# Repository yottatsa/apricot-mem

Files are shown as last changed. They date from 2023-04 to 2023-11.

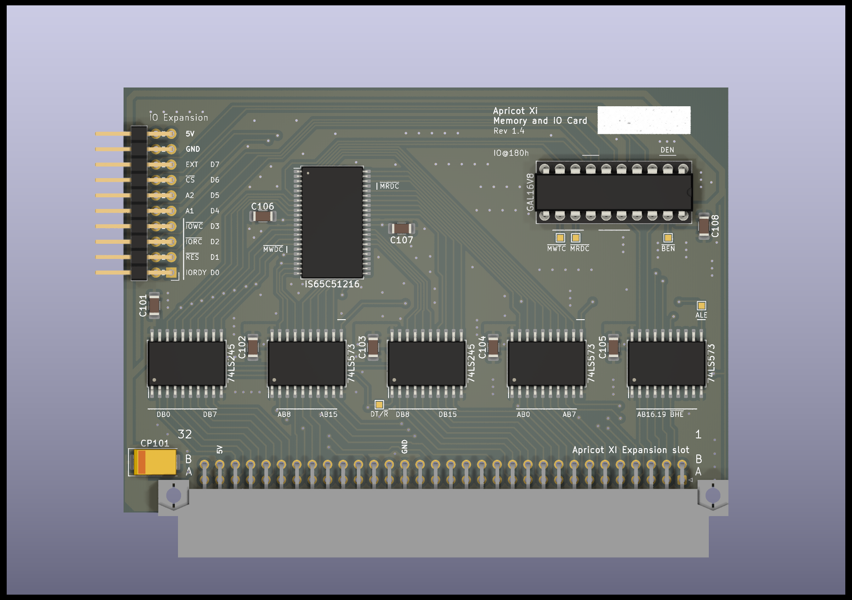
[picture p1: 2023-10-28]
apricot-mem.png

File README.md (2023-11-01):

# Apricot Xi Memory and IO Card 

Additional 640KB RAM, and IO breakout for prototyping.

Tested on PC/Xi, FP. Should be working on F2/F10. Not working on F1e with 128K RAM.

[Schematics](https://kicanvas.org/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), 
[PCB](https://kicanvas.org/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), [Order from AISLER](https://aisler.net/p/DJKRDMKA)

## Building and flashing GAL

    make -C gal
    minipro -p ATF16V8C --write gal/xi.jed -P

## ToDo

* Loading caps on signal lines
* Move GAL to the left so it will be accessible without pulling the card
* Move testpoints to the bottom/make them THT, as it will make it more accessible from the case
* 3D-print a frame to hold the card in place
* DT/R̅ can be latched

## Board verification

- GAL is compilable and flash-able
- pins 12, 19 can not be used as input in registered mode

## Alternative options

* [Apricot F Series expandable SRAM board](https://github.com/stephen-usher/Apricot-RAM-Expansion) by S.R.Usher

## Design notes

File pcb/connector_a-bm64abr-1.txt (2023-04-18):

"Symbol";"Value";"Unit";
"TraceParts.PartNumber";"10-27072010-079244";"";
"REFERENCE";"A-BM64ABR-1";"";
"TraceParts.PartTitle";"DIN 41612, style B, male, 16 - 64 contacts, pitch 2.54mm";"";
"TraceParts.InstanceId";"10-27072010-079244AF7FB7TEG8P7RZZJ1AFMGNGAB";"";
"SUPPLIER";"ASSMANN WSW components";"";
"DESIGN";"DIN 41612, style B, male, pitch 2.54mm, 64ab contacts, Right-angled, Class 1";"";
"TRACEPARTS";"TRACEPARTS";"";
"TraceParts.PartLanguage";"en";"";
"TraceParts.PartVersion";"1.1.8";"";

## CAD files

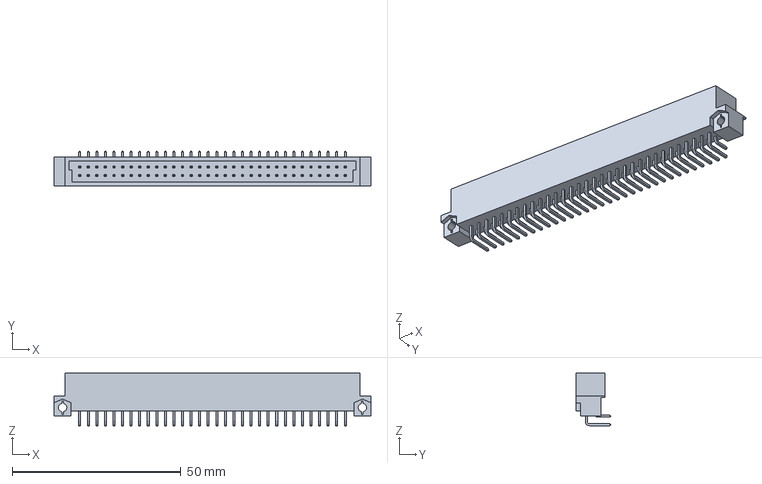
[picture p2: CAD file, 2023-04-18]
pcb/connector_a-bm64abr-1.stp
94.0 x 10.3 x 15.6 mm

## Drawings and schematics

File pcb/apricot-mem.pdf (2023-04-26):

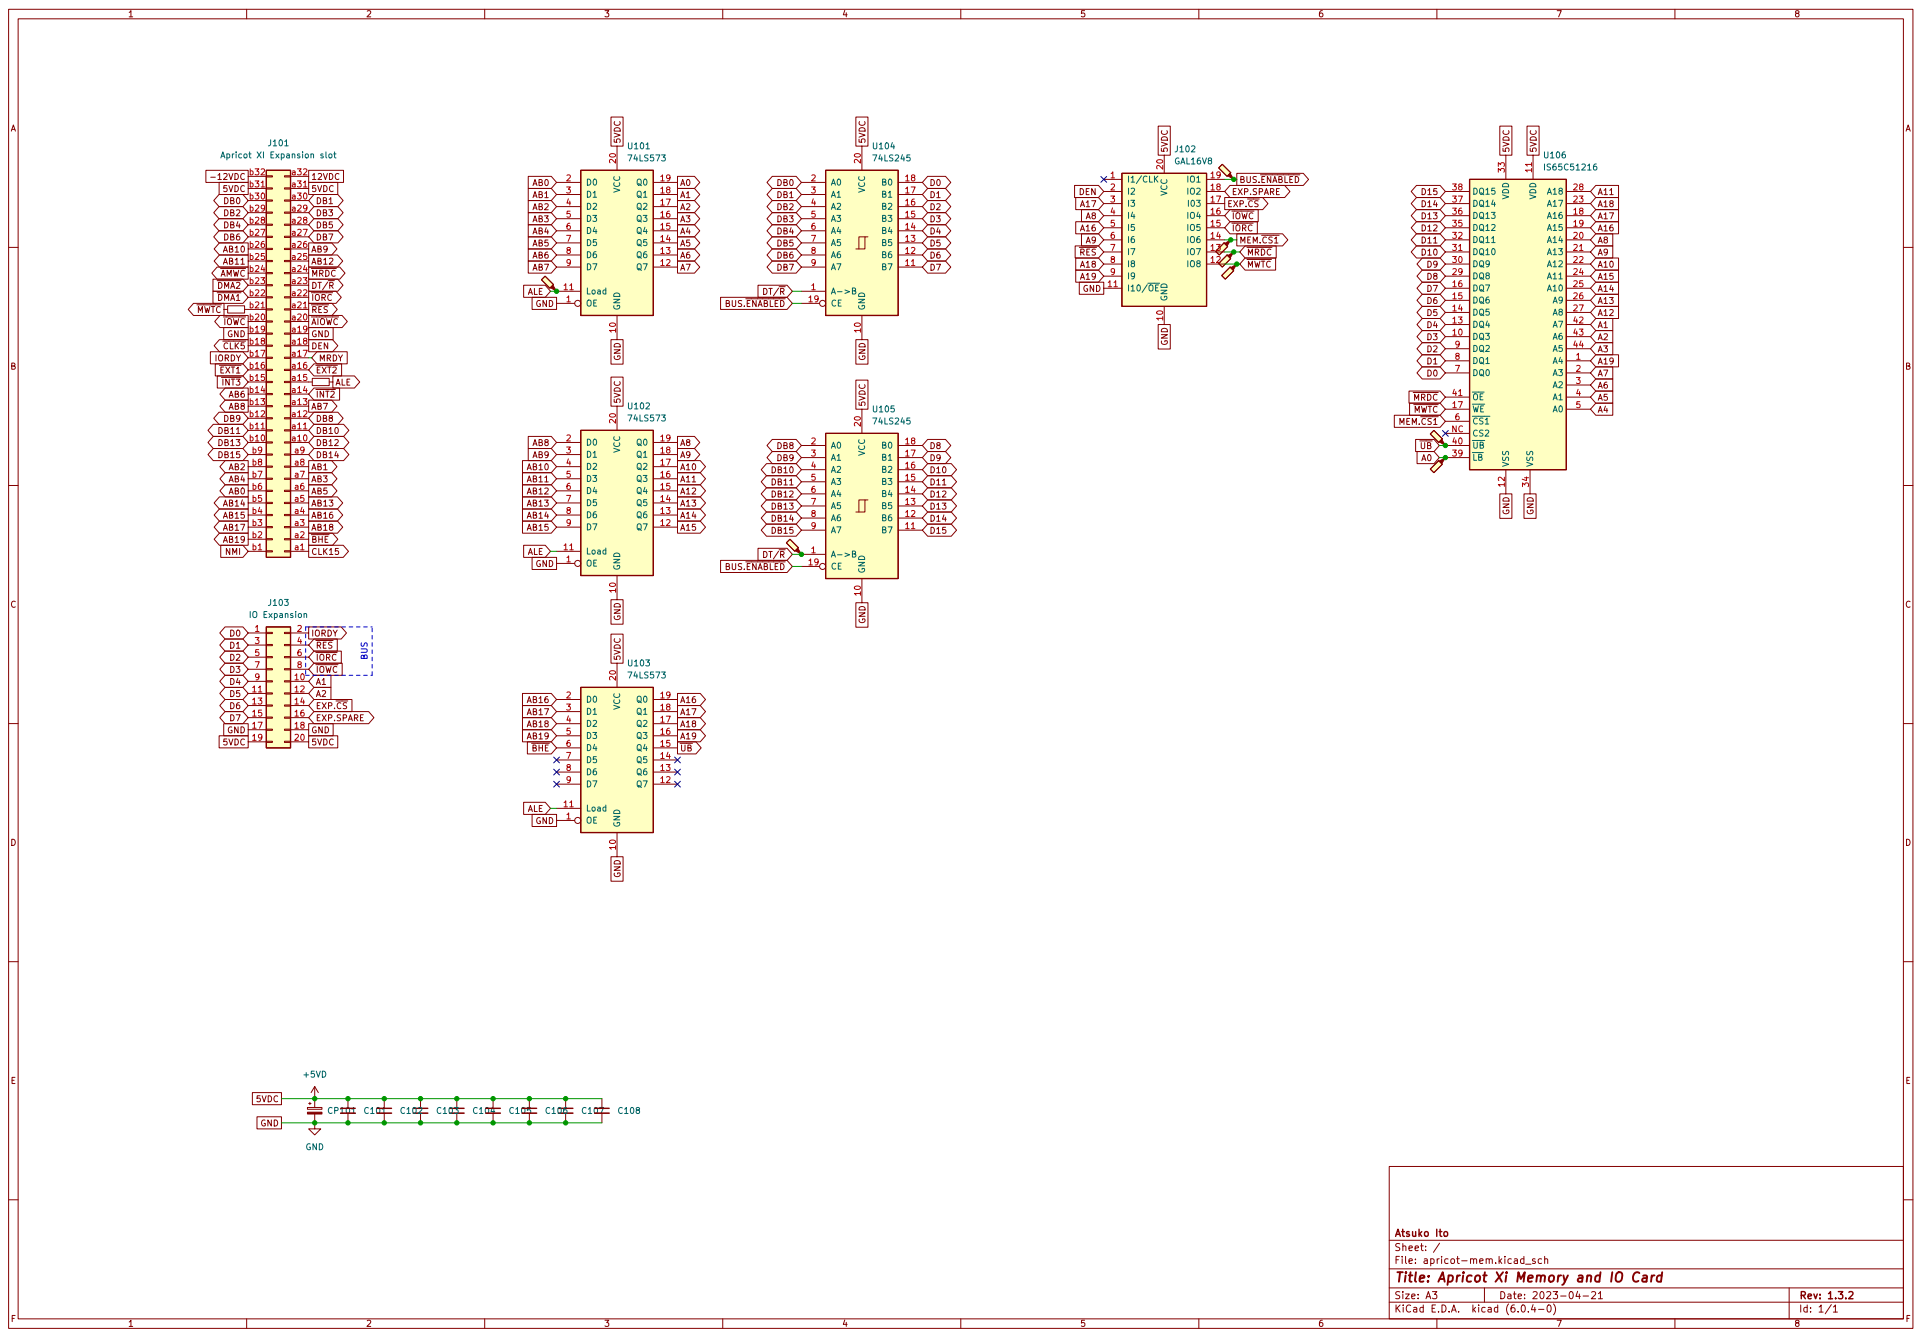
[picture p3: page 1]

~{IOWC} EXP.~{CS} MEM.~{CS1} BUS.~{ENABLED} GND

File: apricot-mem.kicad_sch Sheet: / Atsuko Ito

Id: 1/1 Title: Apricot Xi Memory and IO Card

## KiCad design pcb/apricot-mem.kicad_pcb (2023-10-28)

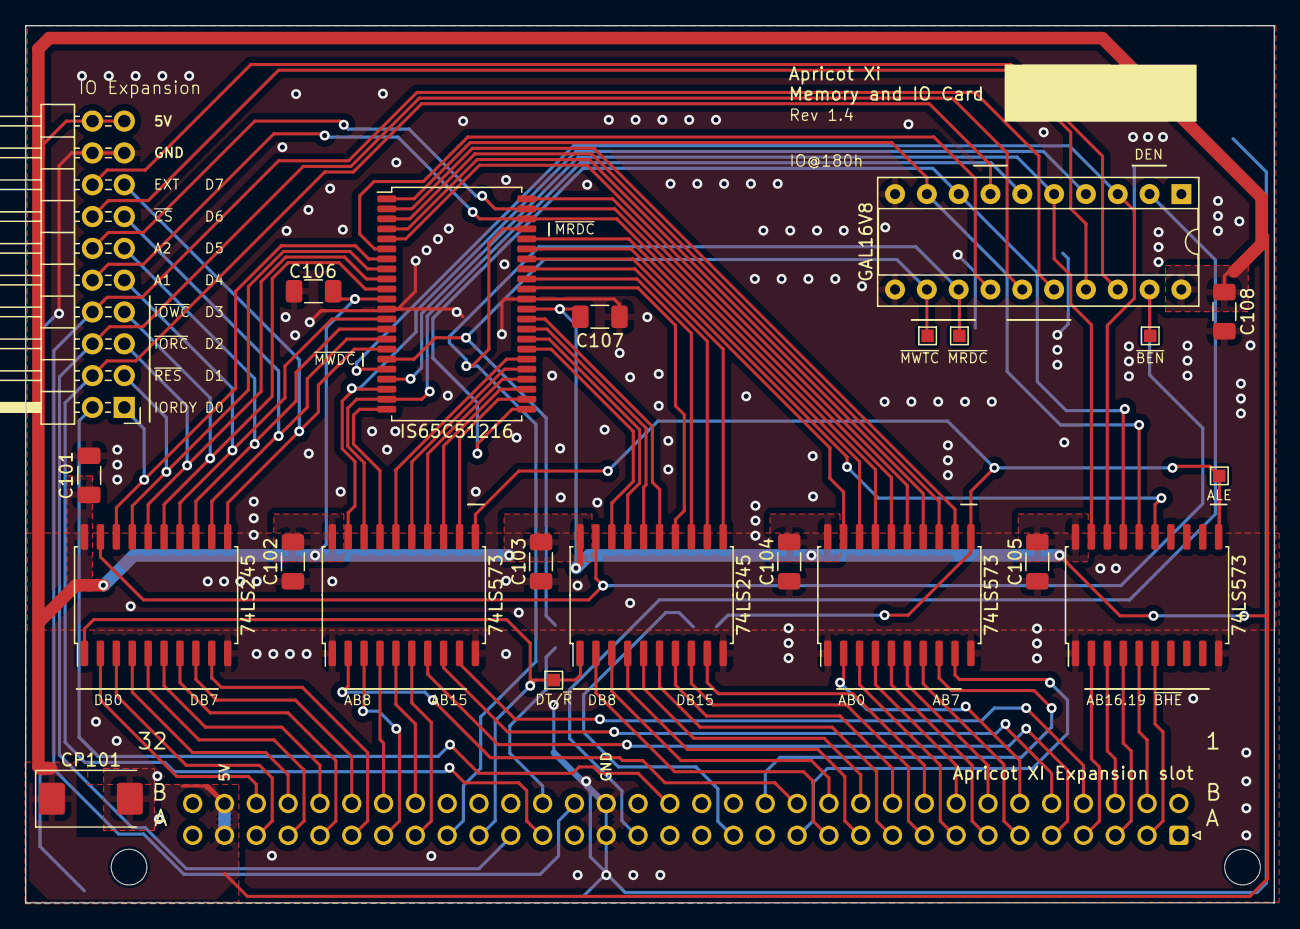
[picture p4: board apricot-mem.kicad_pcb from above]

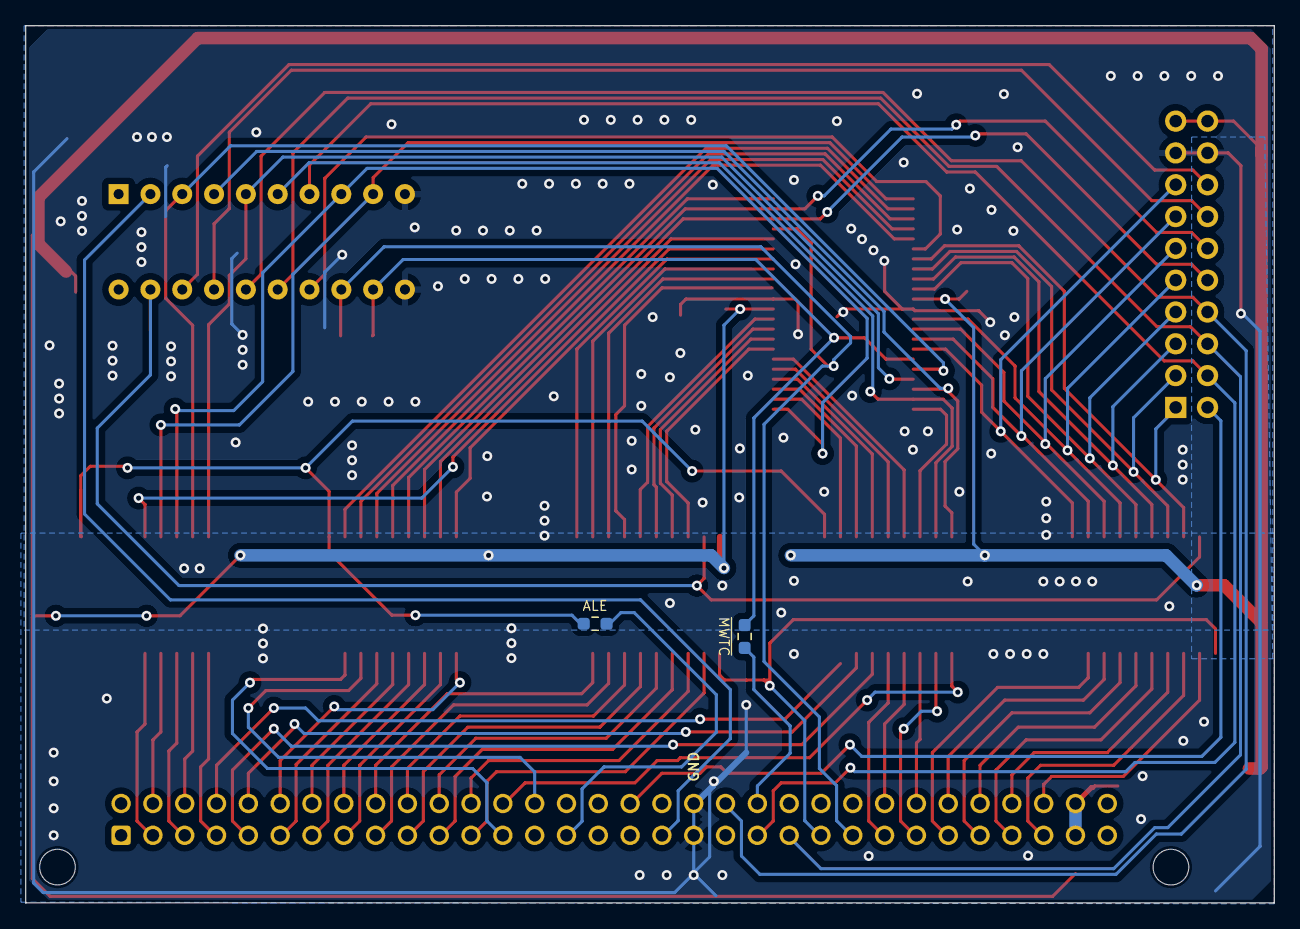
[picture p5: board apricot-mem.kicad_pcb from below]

Board: 2 copper layers, 99.7 x 70.0 mm, 25 parts (2 on the bottom side), 91 nets.

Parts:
C101, C102, C103, C104, C105, C106, C107, C108: 1uF PWR; C_1206_3216Metric_Pad1.33x1.80mm_HandSolder
CP101: PPWR; CP_EIA-7343-31_Kemet-D
J101: Apricot XI Expansion slot; DIN41612_B_2x32_Male_Horizontal_THT
J102: GAL16V8; DIP-20_W7.62mm_Socket
J103: IO Expansion; PinHeader_2x10_P2.54mm_Horizontal
R101: ~{MWTC}; R_0603_1608Metric_Pad0.98x0.95mm_HandSolder
R102: ALE; R_0603_1608Metric_Pad0.98x0.95mm_HandSolder
TP101: ALE; TestPoint_Pad_1.0x1.0mm
TP104: ~{MRDC}; TestPoint_Pad_1.0x1.0mm
TP105: ~{BEN}; TestPoint_Pad_1.0x1.0mm
TP106: DT/~{R}; TestPoint_Pad_1.0x1.0mm
TP107: ~{MWTC}; TestPoint_Pad_1.0x1.0mm
U101, U102, U103: 74LS573; SOIC-20W_7.5x12.8mm_P1.27mm
U104, U105: 74LS245; SOIC-20W_7.5x12.8mm_P1.27mm
U106: IS65C51216; TSOP-II-44_10.16x18.41mm_P0.8mm

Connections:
5VDC: C101.1, C102.1, C103.1, C104.1, C105.1, C106.1, C107.1, C108.1, CP101.1, J101.a31, J101.b31, J102.20 (VCC), J103.19, J103.20, U101.20 (VCC), U102.20 (VCC), U103.20 (VCC), U104.20 (VCC), U105.20 (VCC), U106.11 (VDD), U106.33 (VDD)
A0: U101.19 (Q0), U106.39 (~LB)
A1: J103.10, U101.18 (Q1), U106.42 (A7)
A2: J103.12, U101.17 (Q2), U106.43 (A6)
A3: U101.16 (Q3), U106.44 (A5)
A4: U101.15 (Q4), U106.5 (A0)
A5: U101.14 (Q5), U106.4 (A1)
A6: U101.13 (Q6), U106.3 (A2)
A7: U101.12 (Q7), U106.2 (A3)
A8: J102.4 (I4), U102.19 (Q0), U106.20 (A14)
A9: J102.6 (I6), U102.18 (Q1), U106.21 (A13)
A10: U102.17 (Q2), U106.22 (A12)
A11: U102.16 (Q3), U106.28 (A18)
A12: U102.15 (Q4), U106.27 (A8)
A13: U102.14 (Q5), U106.26 (A9)
A14: U102.13 (Q6), U106.25 (A10)
A15: U102.12 (Q7), U106.24 (A11)
A16: J102.5 (I5), U103.19 (Q0), U106.19 (A15)
A17: J102.3 (I3), U103.18 (Q1), U106.18 (A16)
A18: J102.8 (I8), U103.17 (Q2), U106.23 (A17)
A19: J102.9 (I9), U103.16 (Q3), U106.1 (A4)
AB0: J101.b6, U101.2 (D0)
AB1: J101.a8, U101.3 (D1)
AB2: J101.b8, U101.4 (D2)
AB3: J101.a7, U101.5 (D3)
AB4: J101.b7, U101.6 (D4)
AB5: J101.a6, U101.7 (D5)
AB6: J101.b14, U101.8 (D6)
AB7: J101.a13, U101.9 (D7)
AB8: J101.b13, U102.2 (D0)
AB9: J101.a26, U102.3 (D1)
AB10: J101.b26, U102.4 (D2)
AB11: J101.b25, U102.5 (D3)
AB12: J101.a25, U102.6 (D4)
AB13: J101.a5, U102.7 (D5)
AB14: J101.b5, U102.8 (D6)
AB15: J101.b4, U102.9 (D7)
AB16: J101.a4, U103.2 (D0)
AB17: J101.b3, U103.3 (D1)
AB18: J101.a3, U103.4 (D2)
AB19: J101.b2, U103.5 (D3)
ALE: R102.2, TP101.1, U101.11 (Load), U102.11 (Load), U103.11 (Load)
BUS.~ENABLED: J102.19 (IO1), TP105.1, U104.19 (CE), U105.19 (CE)
D0: J103.1, U104.18 (B0), U106.7 (DQ0)
D1: J103.3, U104.17 (B1), U106.8 (DQ1)
D2: J103.5, U104.16 (B2), U106.9 (DQ2)
D3: J103.7, U104.15 (B3), U106.10 (DQ3)
D4: J103.9, U104.14 (B4), U106.13 (DQ4)
D5: J103.11, U104.13 (B5), U106.14 (DQ5)
D6: J103.13, U104.12 (B6), U106.15 (DQ6)
D7: J103.15, U104.11 (B7), U106.16 (DQ7)
D8: U105.18 (B0), U106.29 (DQ8)
D9: U105.17 (B1), U106.30 (DQ9)
D10: U105.16 (B2), U106.31 (DQ10)
D11: U105.15 (B3), U106.32 (DQ11)
D12: U105.14 (B4), U106.35 (DQ12)
D13: U105.13 (B5), U106.36 (DQ13)
D14: U105.12 (B6), U106.37 (DQ14)
D15: U105.11 (B7), U106.38 (DQ15)
DB0: J101.b30, U104.2 (A0)
DB1: J101.a30, U104.3 (A1)
DB2: J101.b29, U104.4 (A2)
DB3: J101.a29, U104.5 (A3)
DB4: J101.b28, U104.6 (A4)
DB5: J101.a28, U104.7 (A5)
DB6: J101.b27, U104.8 (A6)
DB7: J101.a27, U104.9 (A7)
DB8: J101.a12, U105.2 (A0)
DB9: J101.b12, U105.3 (A1)
DB10: J101.a11, U105.4 (A2)
DB11: J101.b11, U105.5 (A3)
DB12: J101.a10, U105.6 (A4)
DB13: J101.b10, U105.7 (A5)
DB14: J101.a9, U105.8 (A6)
DB15: J101.b9, U105.9 (A7)
DEN: J101.a18, J102.2 (I2)
DT/~R: J101.a23, TP106.1, U104.1 (A->B), U105.1 (A->B)
EXP.SPARE: J102.18 (IO2), J103.16
EXP.~CS: J102.17 (I03), J103.14
GND: C101.2, C102.2, C103.2, C104.2, C105.2, C106.2, C107.2, C108.2, CP101.2, J101.a19, J101.b19, J102.10 (GND), J102.11 (I10/~OE), J103.17, J103.18, U101.1 (OE), U101.10 (GND), U102.1 (OE), U102.10 (GND), U103.1 (OE), U103.10 (GND), U104.10 (GND), U105.10 (GND), U106.12 (VSS), U106.34 (VSS)
IORDY: J101.b17, J103.2
MEM.~CS1: J102.14 (IO6), U106.6 (~CS1)
unnamed: J101.a15, R102.1
unnamed: J101.b21, R101.2
~BHE: J101.a2, U103.6 (D4)
~IORC: J101.a22, J102.15 (IO5), J103.6
~IOWC: J101.b20, J102.16 (IO4), J103.8
~MRDC: J101.a24, J102.13 (IO7), TP104.1, U106.41 (~OE)
~MWTC: J102.12 (IO8), R101.1, TP107.1, U106.17 (~WE)
~RES: J101.a21, J102.7 (I7), J103.4
~UB: U103.15 (Q4), U106.40 (~UB)

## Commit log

2023-04-19 fixing r1.3
    [apricot-mem.kicad_sch]
2023-04-21 r1.3.2 working revision
    [apricot-mem.kicad_pcb, apricot-mem.kicad_sch]
2023-10-28 PCB Revision 1.4
    * better ground plane
    * link to AISLER
    [apricot-mem.kicad_pcb]
